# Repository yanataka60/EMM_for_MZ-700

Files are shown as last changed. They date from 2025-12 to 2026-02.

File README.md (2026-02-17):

# EMMボード for MZ-700

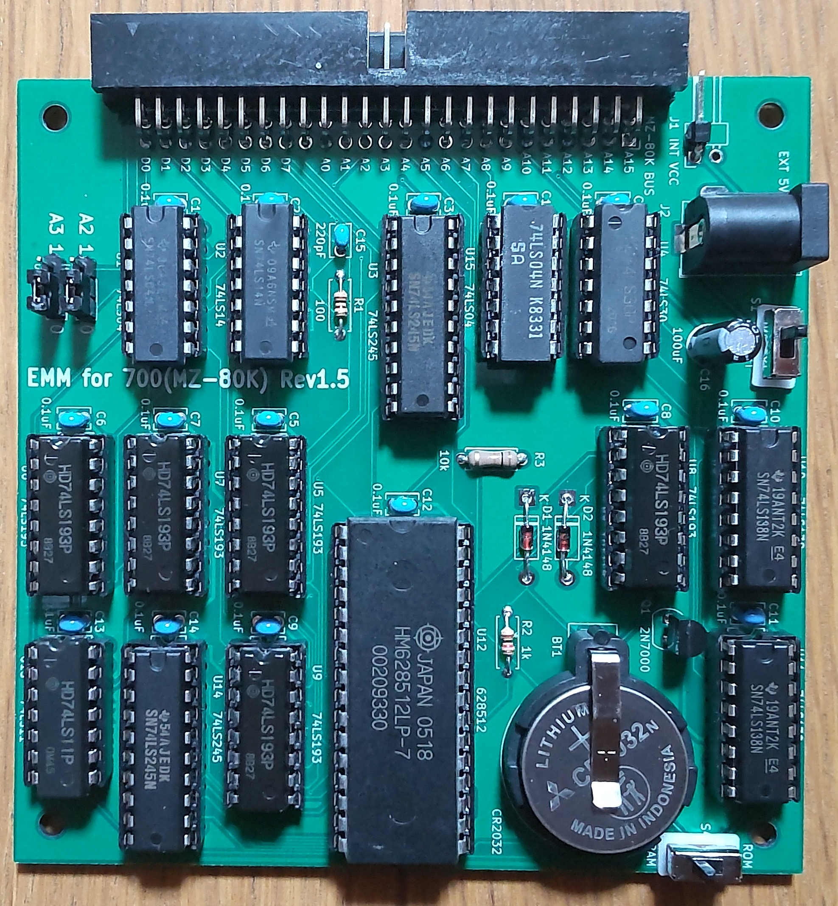
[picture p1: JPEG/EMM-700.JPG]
TITLE


　MZ-700、MZ-80K、MZ-80C、MZ-1200、MZ-1500用の512K S-RAM EMMボードを作ってみました。

　EMMが対応しているHuBASICはMZ-700用だけです。MZ-80K用、MZ-1500用HuBASICはEMMに対応していないので外部記憶装置として使うためにはI/Oポートを直接制御して読み書きする必要があります。

　特徴としては、

　1)I/Oポートは、I・Oデータ機器 PIO-3034互換なのでそのままPIO-3034(320K EMM)として使えます。

　2)CR-2032のバックアップにより電源を切ってもメモリ内容が保持されます。(Rev1.5のバックアップ期間は計算上数年は大丈夫です。)

　3)スイッチにより書込み禁止にできます。

　4)I/Oポートから直接EMMを読み書きすれば512K外部RAMとして使えます。

　5)MZ-700_SD、MZ-80K_SD、MZ-1500_SDと併用すれば512KまるごとSDカードからLOAD、SAVEが可能です。

　6)ジャンパによりEMM0～EMM3のいずれかに設定して使えます。

　7)おまけでアドレスカウンタリセットを付けました。

#### 注)　出来ればMZ-700本体内から5Vを取り出し、EMMボードに供給してください。

#### 　　 電源アダプタを接続しての外部電源で使用する場合には次の順序で電源の入り切りを行わないとバックアップが正常に行われません。ただし、S4スイッチがROM側になっていれば電源入り切りの順番に影響されません。

#### 　　 1)電源を入れるときにはEMMボードより先にMZ-700本体の電源を入れる。

#### 　　 2)電源を切るときには先にEMMボードの電源を切ってからMZ-700本体の電源を切る。

　なお、MZ-700、MZ-80K、MZ-1500本体の通常の電源ON/OFFでの正常動作は確認していますが、電源ON/OFFを瞬間的に繰り返すような無理な使い方をするとEMMのバックアップが正常に動作しないことがあります。電源ON/OFFを瞬間的に繰り返すと電源ユニット(電源アダプタ)にもダメージが及ぶこともあるので電源ON/OFFは間をおいて行ってください。

## 回路図
[回路図](https://github.com/yanataka60/EMM_for_MZ-700/blob/main/KiCad/MZ700_EMM.pdf)
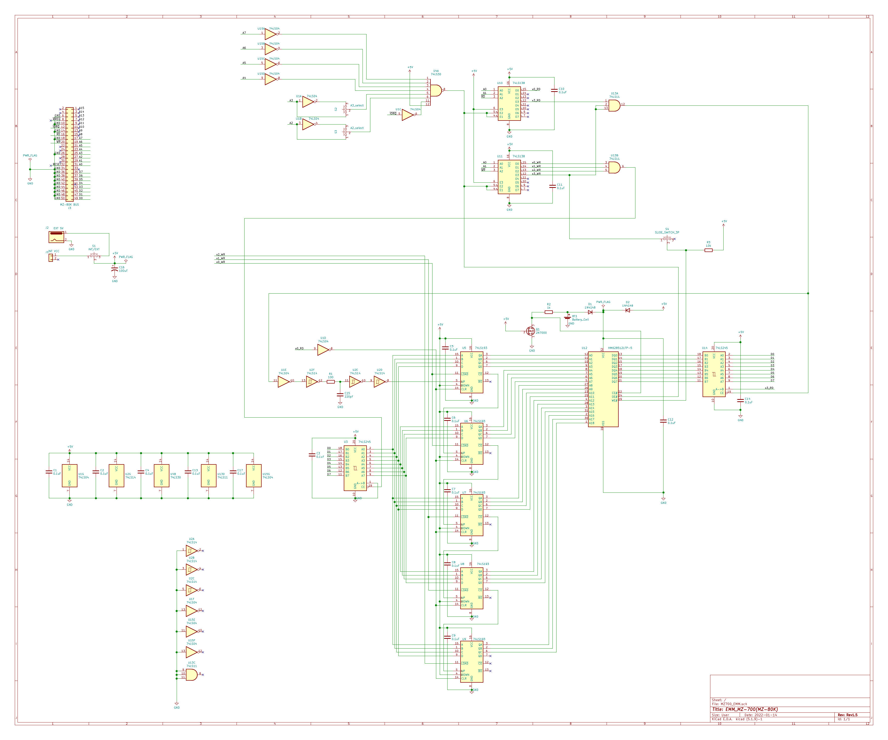
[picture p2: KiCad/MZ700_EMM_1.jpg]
回路図


## 部品表
|番号|品名|数量|備考|
| --- | --- | --- | --- |
|C1-C14,C17|積層セラミックコンデンサ 0.1uF|15||
|C15|積層セラミックコンデンサ 220pF|1||
|C16|電解コンデンサ 100uF|1||
|D1-D2|ダイオード 1N4148|2|1S4から1N4148に変更|
|Q1|FET 2N7000|1||
|J1|コネクタ 2Pin|1|ピンヘッダで代用するときはGNDと間違えないよう1Pinで5Vだけにしたほうが良い|
|J2|DCジャック|1||
|R1|カーボン抵抗 100Ω|1||
|R2|カーボン抵抗 1k|1||
|R3|カーボン抵抗 10k|1||
|S1|3Pスライドスイッチ|1|秋月電子通商 SS12D01G4など|
|S2,S3|3Pスライドスイッチ又は1x3ピンヘッダとジャンパーピン|1|秋月電子通商 SS12D01G4又はPH-1X3SG,MJ-254-6BK等|
|S4|3Pスライドスイッチ|1|秋月電子通商 SS12D01G4など|
|U1,U15|74LS04|2|樫木総業等|
|U2|74LS14|1|樫木総業等|
|U3,U14|74LS245|2|樫木総業等|
|U4|74LS30|1|樫木総業等|
|U5-U9|74LS193|5|樫木総業等|
|U10,U11|74LS138|2|樫木総業等|
|U12|SRAM HM628512|1|注1)|
|U13|74LS11|1|樫木総業等|
|BT1|ボタン電池基板取付用ホルダー CR2032用(小型タイプ)|1|秋月電子通商 CH25-2032LFなど|

注1)DIPで設計しています。SOPを入手した場合にはこちらの変換基板を使うことで装着できます。

https://github.com/yanataka60/SOPtoDIP32

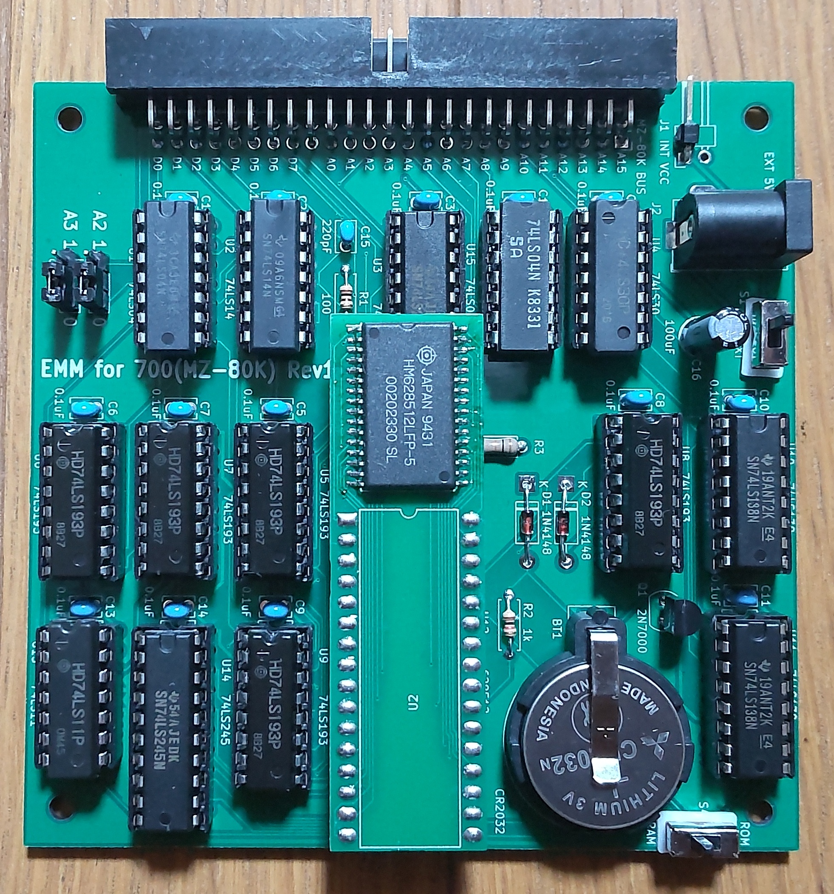
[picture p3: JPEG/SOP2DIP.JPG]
SOP2DIP


## I/Oポート
### EMM0
ジャンパピンA3、A2とも0の位置にします。

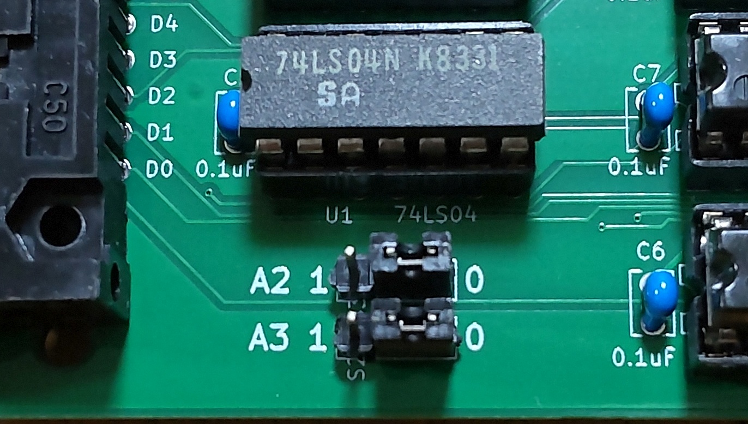
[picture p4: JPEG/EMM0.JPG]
EMM0


|アドレス|R/W|説明|
| --- | --- | --- |
|00h|R|アドレスカウンタリセット|
|00h|W|アドレスカウンタ Bit[7:0]|
|01h|W|アドレスカウンタ Bit[15:8]|
|02h|W|アドレスカウンタ Bit[18:16]|
|03h|R|データ読み出し:アドレスカウンタ+1|
|03h|W|データ書き込み:アドレスカウンタ+1|
### EMM1
ジャンパピンA3を0、A2を1の位置にします。

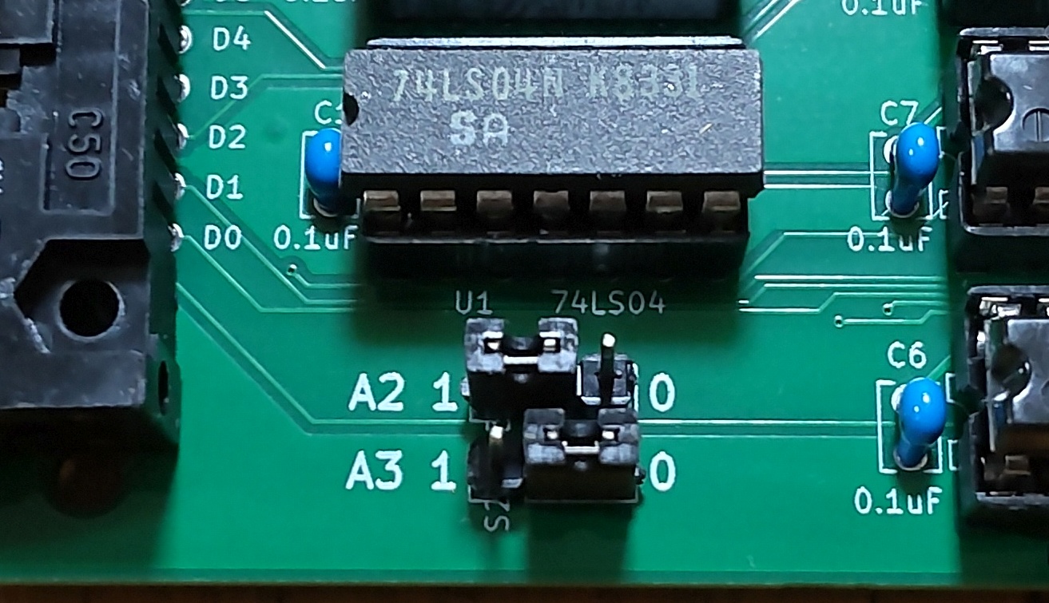
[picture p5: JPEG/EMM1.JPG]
EMM1


|アドレス|R/W|説明|
| --- | --- | --- |
|04h|R|アドレスカウンタリセット|
|04h|W|アドレスカウンタ Bit[7:0]|
|05h|W|アドレスカウンタ Bit[15:8]|
|06h|W|アドレスカウンタ Bit[18:16]|
|07h|R|データ読み出し:アドレスカウンタ+1|
|07h|W|データ書き込み:アドレスカウンタ+1|
### EMM2
ジャンパピンA3を1、A2を0の位置にします。

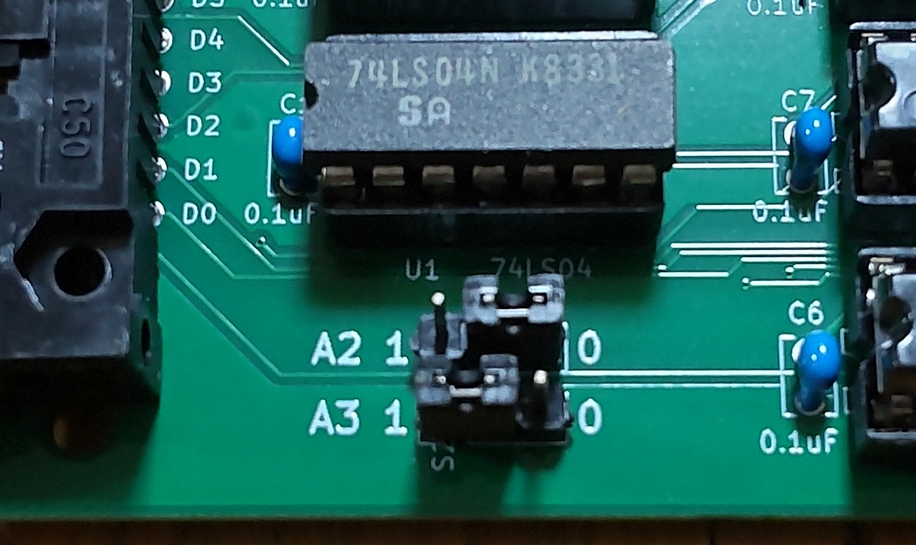
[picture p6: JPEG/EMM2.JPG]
EMM2


|アドレス|R/W|説明|
| --- | --- | --- |
|08h|R|アドレスカウンタリセット|
|08h|W|アドレスカウンタ Bit[7:0]|
|09h|W|アドレスカウンタ Bit[15:8]|
|0Ah|W|アドレスカウンタ Bit[18:16]|
|0Bh|R|データ読み出し:アドレスカウンタ+1|
|0Bh|W|データ書き込み:アドレスカウンタ+1|
### EMM3
ジャンパピンA3、A2とも1の位置にします。

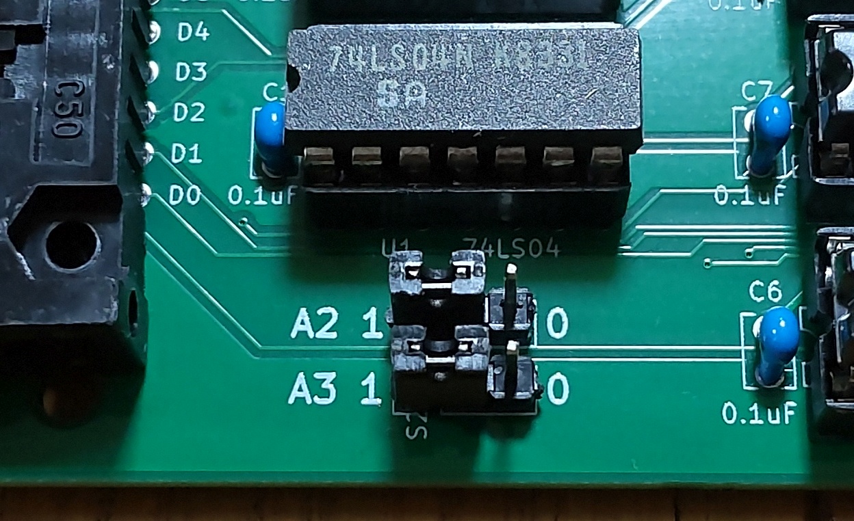
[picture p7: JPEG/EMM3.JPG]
EMM3


|アドレス|R/W|説明|
| --- | --- | --- |
|0Ch|R|アドレスカウンタリセット|
|0Ch|W|アドレスカウンタ Bit[7:0]|
|0Dh|W|アドレスカウンタ Bit[15:8]|
|0Eh|W|アドレスカウンタ Bit[18:16]|
|0Fh|R|データ読み出し:アドレスカウンタ+1|
|0Fh|W|データ書き込み:アドレスカウンタ+1|

## SAMPLEプログラム
　SAMPLEフォルダ内にEMMMENU、EMMCHECK、EMMTESTを置きました。

　使い方については、フォルダ内のREADME.mdを参照してください。

## EMMからの起動
　せっかくバッテリーバックアップに対応させたのでMZ-700_SD、MZ-1500_SDからコマンド「FDE0」～「FDE3」を使うことで「EMM0」～「EMM3」のHuBASICを起動できるようにしてみました。

　MZ-700_SD、MZ-1500_SDのROMをEMM対応に書き換える必要があります。

　MZ-700_SD、MZ-1500_SDの「EMMボード for MZ-700からの起動」を参照してください。

　https://github.com/yanataka60/MZ-700_SD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

　https://github.com/yanataka60/MZ-1500_SD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

## 初期基板をバッテリーバックアップ対応とするには
#### 2026.2.17 Rev1.5基板ではバックアップ時間が飛躍的に増加し、ICに負荷をかけない回路となりました。バッテリーバックアップを使うなら出来ればRev1.5基板に更新してください。

　以下に示すパターンカット、ジャンパ、追加部品(抵抗10k×1本、ダイオード1S4×1本)で改造することで初期基板をバッテリーバックアップ対応とすることが可能です。

　ただし、パターンカット個所がU13 74LS11、U15 74LS04のICソケット内側にもあるのでEMMボード組み立て済みの場合にはICソケットを一旦取り外す必要があります。

### パターンカット個所
　U13 74LS11の9Pin、10Pin、11PinをGNDから切り離します。

　U15 74LS04の11Pin、13PinをGNDから切り離します。

　U12 HM628512の29PinとU11 74LS138 12Pinとの接続をカットします。

　U12 HM628512の22、24Pin、R2 10Kとの接続点とU11 74LS138 5Pinとの接続をカットします。

部品面全体
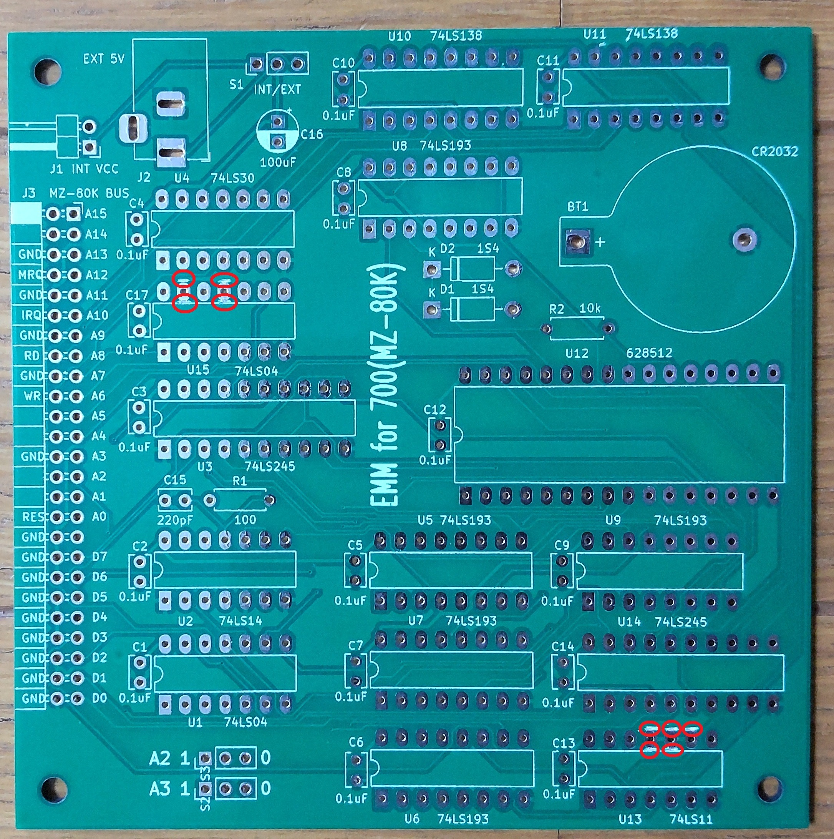
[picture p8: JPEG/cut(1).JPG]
cut1


部品面拡大1
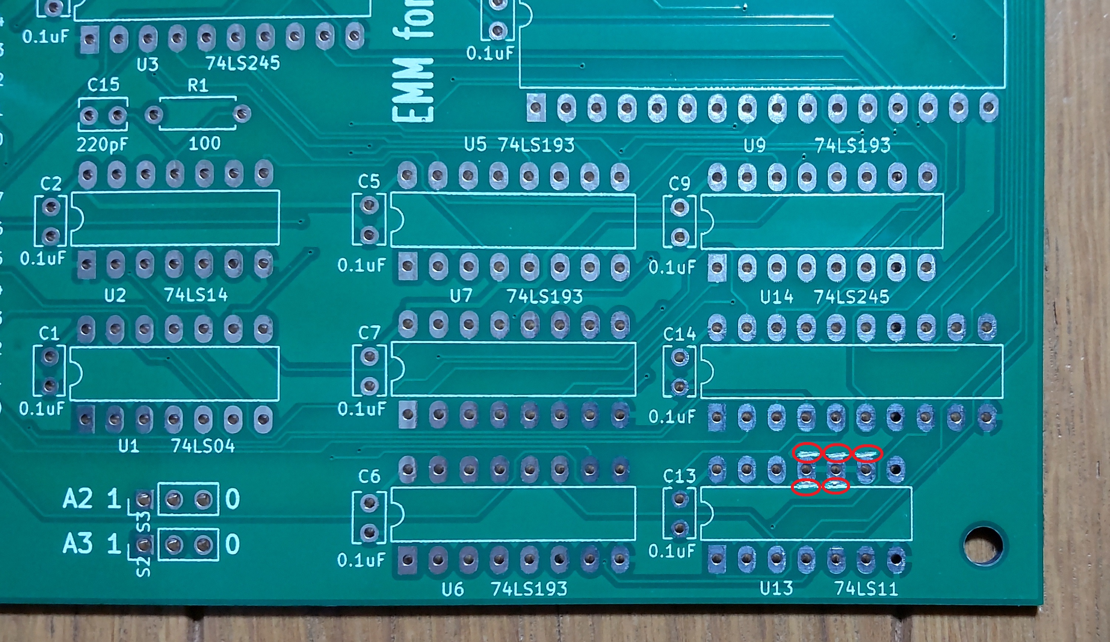
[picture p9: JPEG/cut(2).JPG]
cut2


部品面拡大2
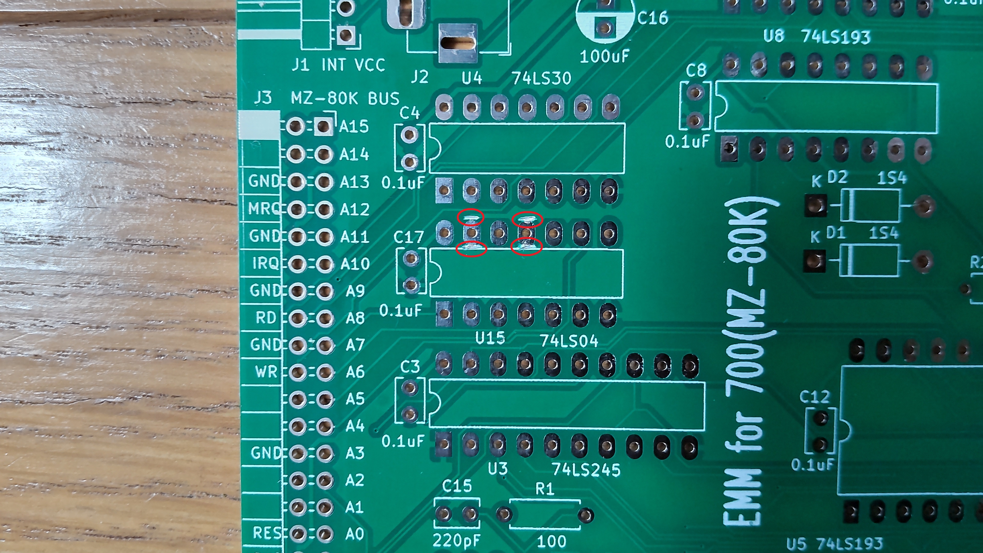
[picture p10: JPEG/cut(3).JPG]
cut3


ハンダ面全体
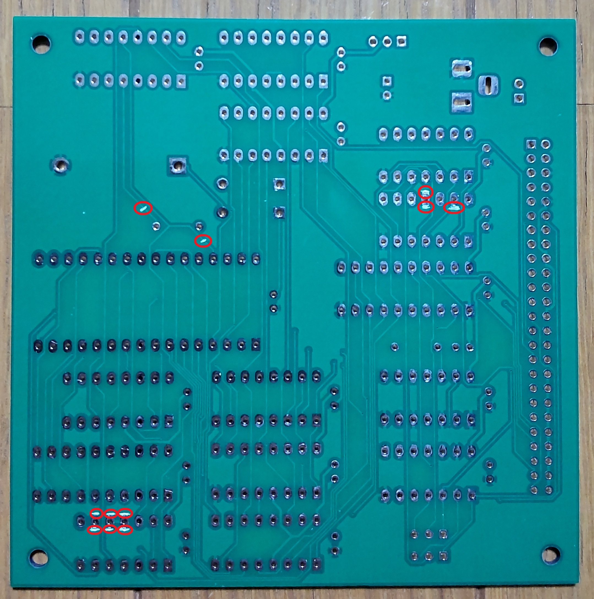
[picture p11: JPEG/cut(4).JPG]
cut4


ハンダ面拡大1
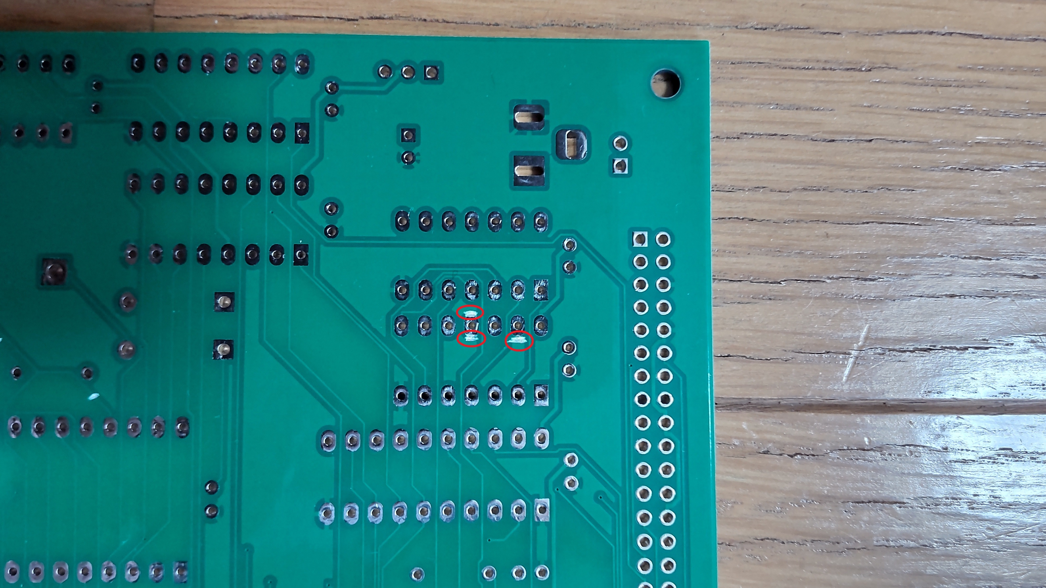
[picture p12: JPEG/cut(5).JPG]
cut5


ハンダ面拡大2
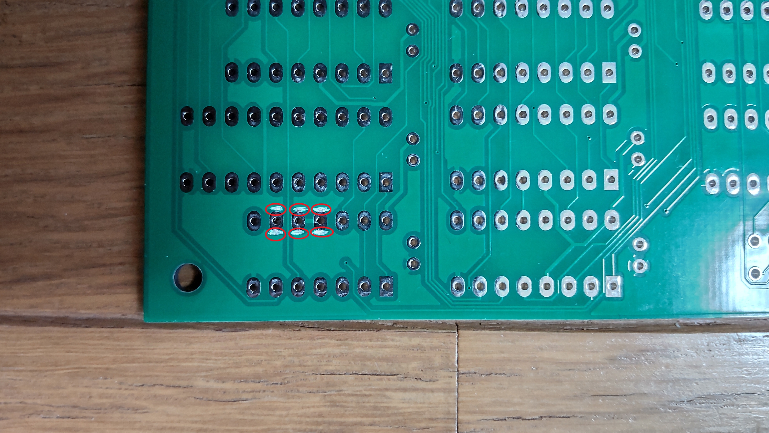
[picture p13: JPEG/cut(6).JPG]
cut6


ハンダ面拡大3
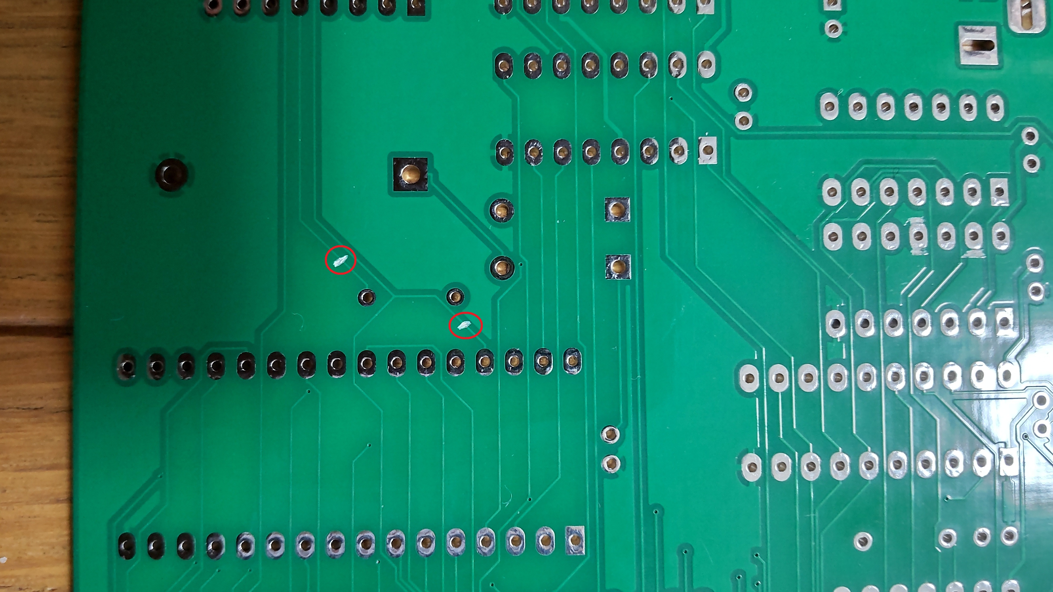
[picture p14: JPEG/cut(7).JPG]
cut7


### ジャンパ個所
　U11 74LS138 5PinとU13 74LS11 11Pin

　U13 74LS11 8PinとU12 HM628512 24Pin(画像ではR2 10KのU12 HM628512 24Pinと接続されている方)

　U11 74LS138 12PinとU15 74LS04 13Pin

　U15 74LS04 12Pinと11Pin

　U15 74LS04 10Pinとダイオード 1S4 アノード

　ダイオード 1S4 カソードとU12 HM628512 29Pin

　U12 HM628512 29Pinと抵抗 10KとU12 HM628512 32Pin

ハンダ面全体
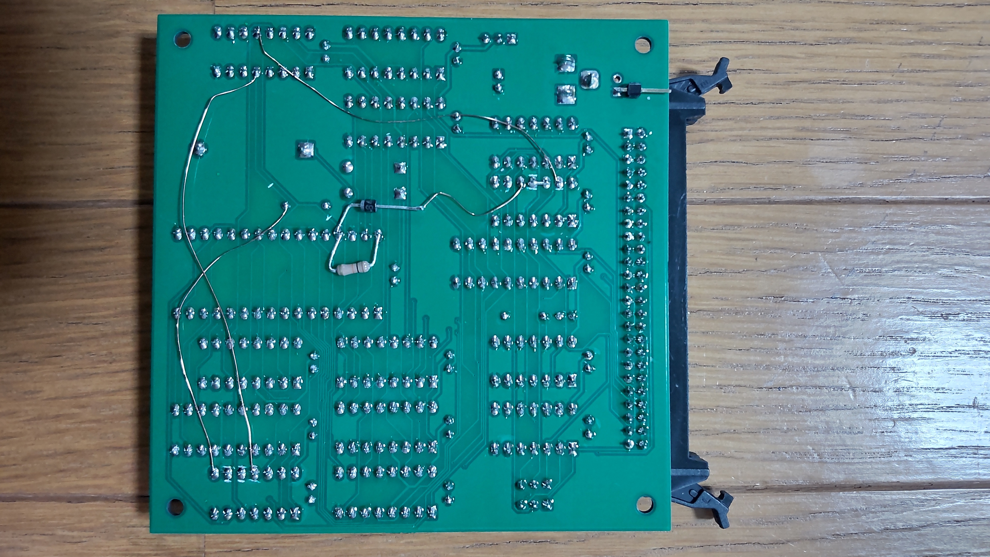
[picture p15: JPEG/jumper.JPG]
jumper


## 追記
2025.12.26 SAMPLEプログラムを追加しました。

2025.12.28 バッテリーバックアップしていてもメモリ内容が変わってしまう症状が時々発生しています。原因と対策を検討中です。

2026.1.1 簡単な修正では症状を抑えることが出来ないのでこのバージョンではバッテリーバックアップは断念し、対策を練りなおします。

2026.1.23 バッテリーバックアップ正常版(Rev1.2)に更新。初期基板をバッテリーバックアップ対応とするための改修方法を記述。

2026.1.23 バックアップ期間について追記。

2026.1.24 HM628512の書き込み時WE信号が瞬間的に5.9Vほどの電圧が掛かることを記述。すーぱーたーぼさんご指摘ありがとうございました。

2026.1.25 D1,D2を1S4から1N4148に変更。AIGOU Yoshiakiさんアドバイスありがとうございました。

2026.2.17 すーぱーたーぼさんに提案していただいていたn-FETを用いたバッテリーバックアップ回路を採用しました。すーぱーたーぼさんアドバイスありがとうございました。

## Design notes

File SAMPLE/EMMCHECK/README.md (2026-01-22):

# EMMCHECK for MZ-700_SD(MZ-80K_SD、MZ-1500_SD)

　EMMボートの512K S-RAMの内容とMZ-700_SD(MZ-80K_SD、MZ-1500_SD)のファイルの内容を比較します。

　MZ-700、MZ-80K、MZ-80C、MZ-1200、MZ-1500で実行可能です。

　バッテリーバックアップが正常に機能しているかチェックするためのプログラムです。

　起動するとまず対象とするEMMをEMM0～EMM3の中から数字で選択します。

　次に比較するファイルを指定します。

　「FNAME:」と聞いてきますので次のうちから選択して入力します。

### [BREAK]キー
　処理が中断されたものとしてMONITOR入力待ちに戻ります。

### DOSファイル名を入力せずそのまま[CR]キー
　選択したEMMに対応するPIO3034_x.mzt(PIO3034_0.mzt、PIO3034_1.mzt、PIO3034_2.mzt、PIO3034_3.mzt)をDOSファイル名として比較します。

### DOSファイル名を入力して[CR]キー
　入力されたDOSファイル名のファイルと比較とします。拡張子の「mzt」は省略可能です。

### *FDL xxx[CR]キー
　SDカードに保存されている文字列xxxから始まるDOSファイル名を一覧表示します。xxxを省略した場合はすべてのファイルが一覧表示対象となります。

　20件表示したところで指示待ちになるので打ち切るならSHIFT+BREAK又は↑を入力すると打ち切られ、Bキーで前の20件に戻ります。それ以外のキーで次の20件を表示します。

　検索結果の行頭には「FNAME:」を付加して表示してあるので比較したいファイルにカーソルキーを合わせて[CR]キーを押すだけで選択が可能です。

例)

FNAME:[CR]

FNAME:PIO-3034EMM1[CR]

FNAME:*FDL PIO[CR]

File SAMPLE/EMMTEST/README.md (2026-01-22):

# EMMTEST

　EMMボートの512K S-RAMの読み書きテストプログラムです。

　MZ-700、MZ-80K、MZ-80C、MZ-1200、MZ-1500で実行可能です。

　RAMの内容を一時退避しながらテストしますのでRAMの読み書きが正常であればEMMの内容が変化してしまうことはありません。

　起動すると対象とするEMMをEMM0～EMM3の中から数字で選択するとテストが始まります。(00000h～7FFFFh)

　書き込んだ内容が正常に読み出せない場合にはエラーと表示して停止します。

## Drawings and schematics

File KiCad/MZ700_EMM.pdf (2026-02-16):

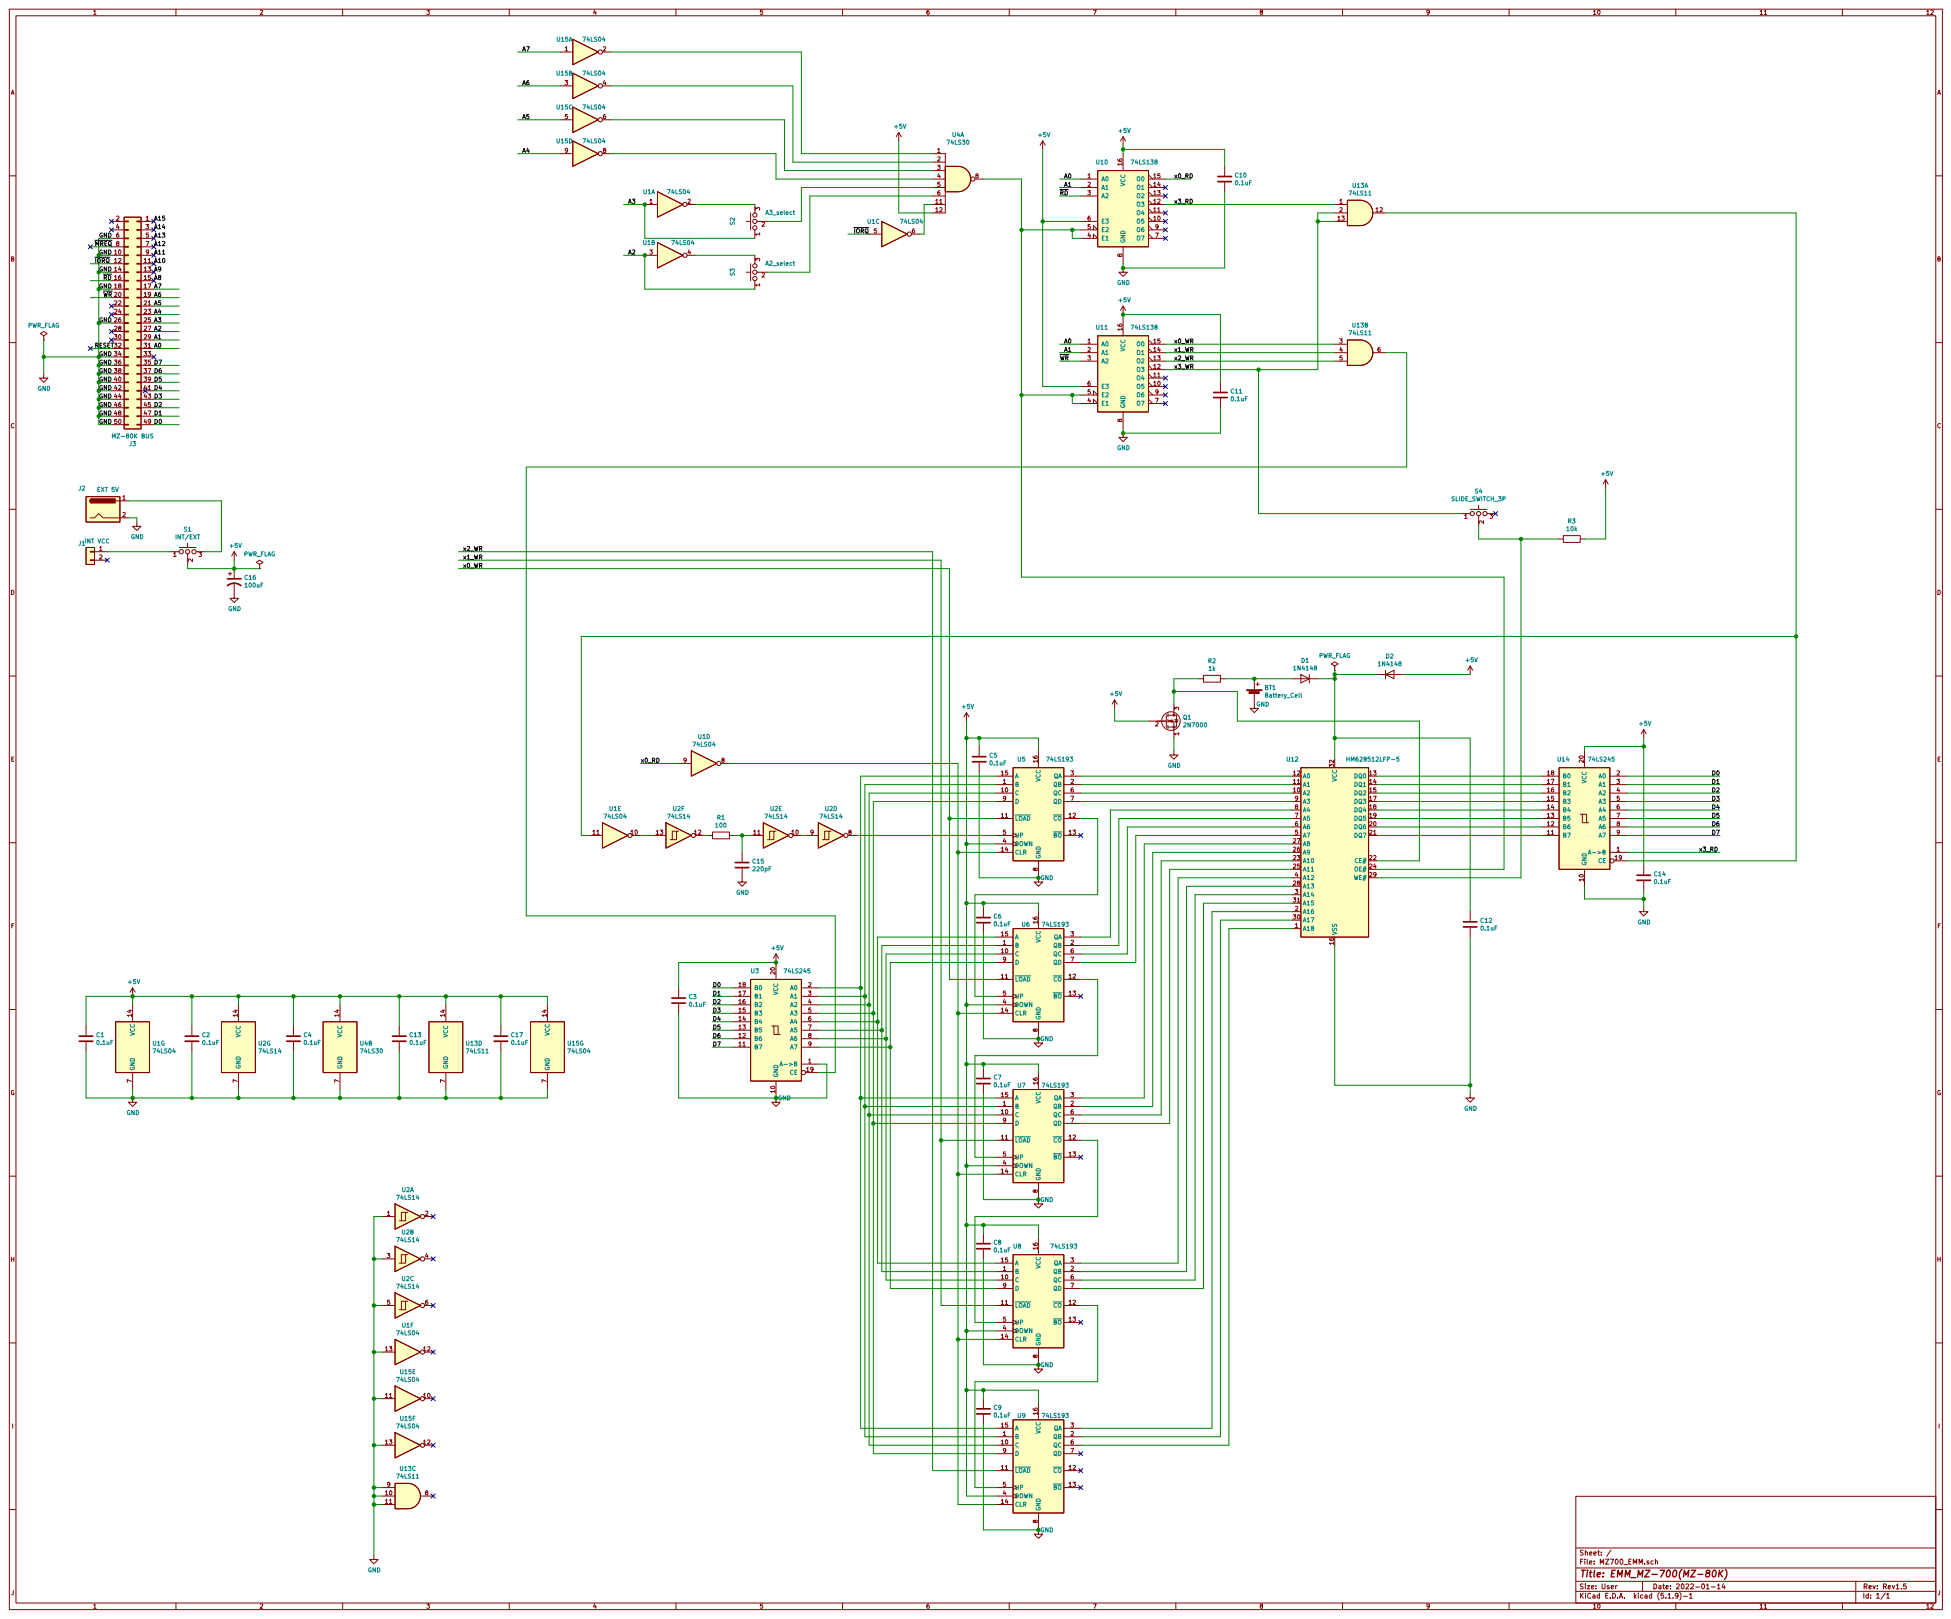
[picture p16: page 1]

GND GNDWR GND GND

RESET GND GND GND GND GND

14 O0 x1_WR | 4
13 O1 x2_WR | 5
12 O2 x3_WR
11 O3

38 | 37
40 | 39
42 | 41
44 | 43
46 | 45
48 | 47
50 | 49

File: MZ700_EMM.sch Sheet: / VCC 14 GND

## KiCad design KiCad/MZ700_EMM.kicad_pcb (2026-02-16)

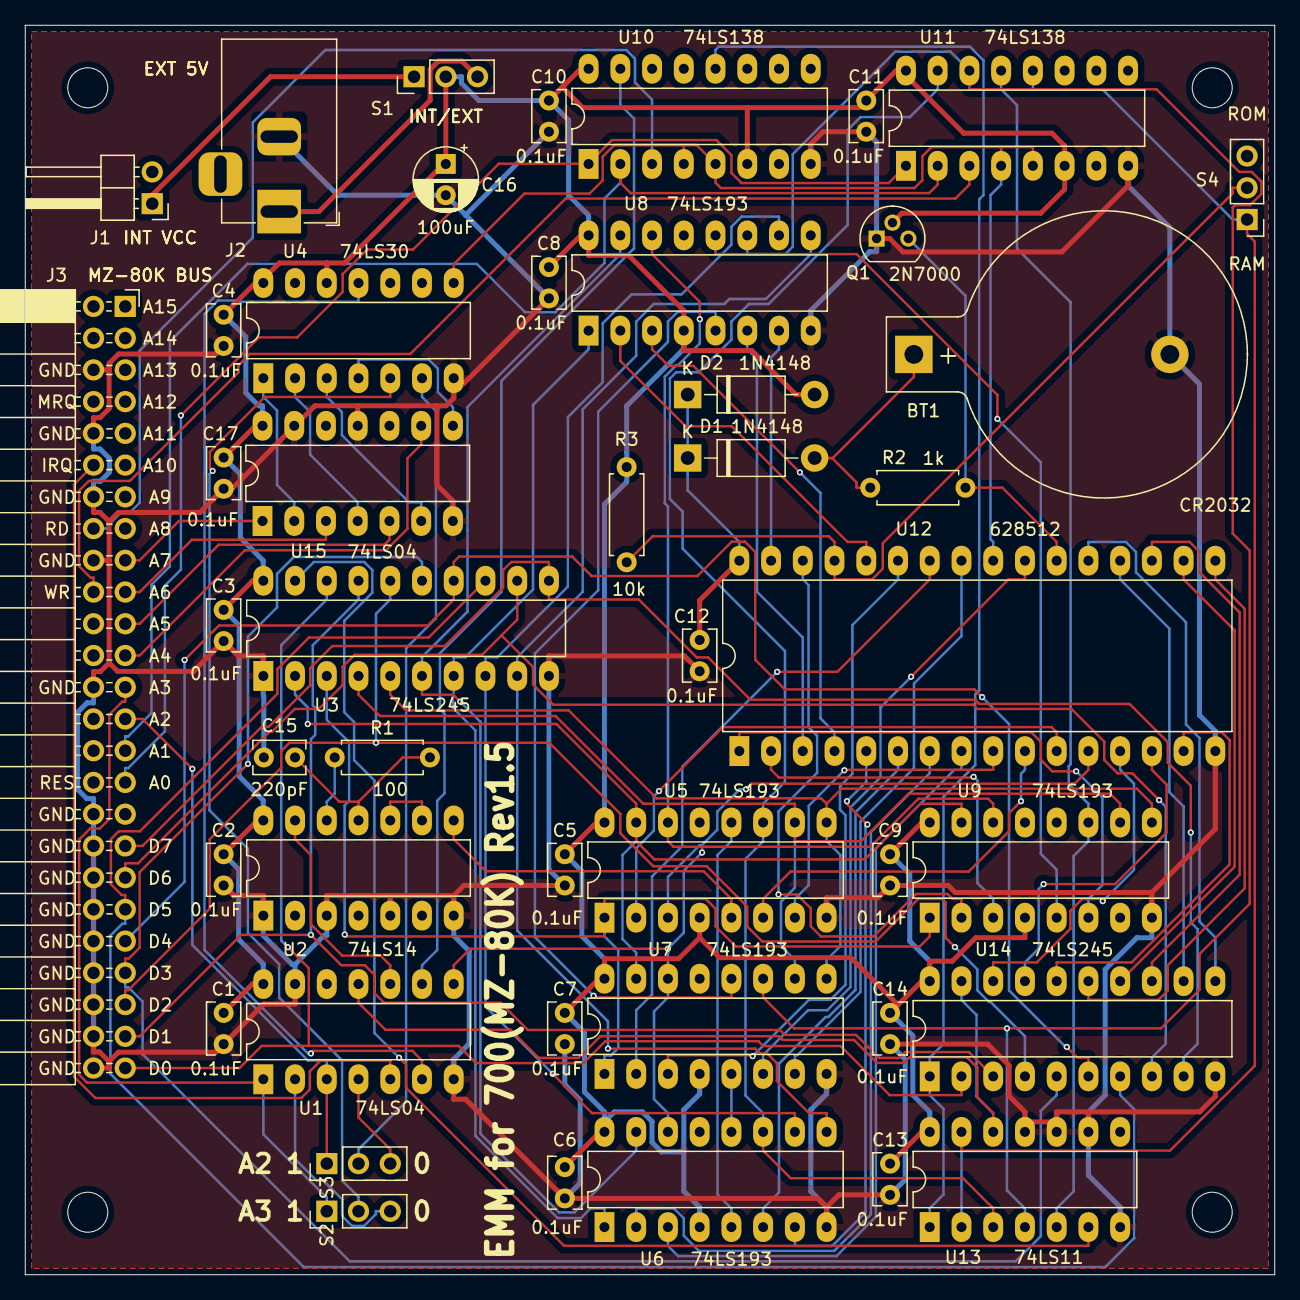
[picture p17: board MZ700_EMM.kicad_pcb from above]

Board: 2 copper layers, 100.0 x 100.0 mm, 50 parts (0 on the bottom side), 90 nets.

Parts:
BT1: Battery_Cell; BatteryHolder_Keystone_103_1x20mm
C1, C2, C3, C4, C5, C6, C7, C8, C9, C10, C11, C12, C13, C14, C17: 0.1uF; C_Rect_L4.0mm_W2.5mm_P2.50mm
C15: 220pF; C_Rect_L4.0mm_W2.5mm_P2.50mm
C16: 100uF; CP_Radial_D5.0mm_P2.50mm
D1, D2: 1N4148; D_DO-41_SOD81_P10.16mm_Horizontal
J1: INT VCC; PinHeader_1x02_P2.54mm_Horizontal
J2: EXT 5V; BarrelJack_Horizontal
J3: MZ-80K BUS; PinSocket_2x25_P2.54mm_Horizontal
MH1, MH2, MH3, MH4: MountingHole_3.2mm_M3
Q1: 2N7000; TO-92
R1: 100; R_Axial_DIN0207_L6.3mm_D2.5mm_P7.62mm_Horizontal
R2: 1k; R_Axial_DIN0207_L6.3mm_D2.5mm_P7.62mm_Horizontal
R3: 10k; R_Axial_DIN0207_L6.3mm_D2.5mm_P7.62mm_Horizontal
S1: INT/EXT; PinHeader_1x03_P2.54mm_Vertical
S2: A3_select; PinHeader_1x03_P2.54mm_Vertical
S3: A2_select; PinHeader_1x03_P2.54mm_Vertical
S4: SLIDE_SWITCH_3P; PinHeader_1x03_P2.54mm_Vertical
U1, U15: 74LS04; DIP-14_W7.62mm_LongPads
U2: 74LS14; DIP-14_W7.62mm_LongPads
U3, U14: 74LS245; DIP-20_W7.62mm_LongPads
U4: 74LS30; DIP-14_W7.62mm_LongPads
U5, U6, U7, U8, U9: 74LS193; DIP-16_W7.62mm_LongPads
U10, U11: 74LS138; DIP-16_W7.62mm_LongPads
U12: HM628512LFP-5; DIP-32_W15.24mm_LongPads
U13: 74LS11; DIP-14_W7.62mm_LongPads

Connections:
+5V: C1.1, C2.1, C3.1, C4.1, C5.1, C6.1, C7.1, C8.1, C9.1, C10.1, C11.1, C13.1, C14.1, C16.1, C17.1, D2.2, Q1.2, R3.2, S1.2, U1.14, U2.14, U3.20, U4.12, U4.14, U5.4, U5.16, U6.4, U6.16, U7.4, U7.16, U8.4, U8.16, U9.4, U9.16, U10.6, U10.16, U11.6, U11.16, U13.14, U14.20, U15.14
/A0: J3.31, U10.1, U11.1
/A1: J3.29, U10.2, U11.2
/A2: J3.27, S3.1, U1.3
/A3: J3.25, S2.1, U1.1
/A4: J3.23, U15.9
/A5: J3.21, U15.5
/A6: J3.19, U15.3
/A7: J3.17, U15.1
/D0: J3.49, U3.18, U14.2
/D1: J3.47, U3.17, U14.3
/D2: J3.45, U3.16, U14.4
/D3: J3.43, U3.15, U14.5
/D4: J3.41, U3.14, U14.6
/D5: J3.39, U3.13, U14.7
/D6: J3.37, U3.12, U14.8
/D7: J3.35, U3.11, U14.9
/x0_RD: U1.9, U10.15
/x0_WR: U5.11, U6.11, U11.15, U13.3
/x1_WR: U7.11, U8.11, U11.14, U13.4
/x2_WR: U9.11, U11.13, U13.5
/x3_RD: U10.12, U13.1, U14.1
/x3_WR: S4.1, U11.12, U13.2, U13.13
/~IORQ: J3.12, U1.5
/~RD: J3.16, U10.3
/~WR: J3.20, U11.3
GND: BT1.2, C1.2, C2.2, C3.2, C4.2, C5.2, C6.2, C7.2, C8.2, C9.2, C10.2, C11.2, C12.2, C13.2, C14.2, C15.2, C16.2, C17.2, J2.2, J3.6, J3.10, J3.14, J3.18, J3.26, J3.34, J3.36, J3.38, J3.40, J3.42, J3.44, J3.46, J3.48, J3.50, Q1.1, U1.7, U1.13, U2.1, U2.3, U2.5, U2.7, U3.1, U3.10, U4.7, U5.8, U6.8, U7.8, U8.8, U9.8, U10.8, U11.8, U12.16, U13.7, U13.9, U13.10, U13.11, U14.10, U15.7, U15.11, U15.13
unnamed: BT1.1, D1.2, R2.2
unnamed: C12.1, D1.1, D2.1, U12.32
unnamed: C15.1, R1.2, U2.11
unnamed: J1.1, S1.1
unnamed: J2.1, S1.3
unnamed: Q1.3, R2.1, U12.22
unnamed: R1.1, U2.12
unnamed: R3.1, S4.2, U12.29
unnamed: S2.2, U4.5
unnamed: S2.3, U1.2
unnamed: S3.2, U4.6
unnamed: S3.3, U1.4
unnamed: U1.6, U4.11
unnamed: U1.8, U5.14, U6.14, U7.14, U8.14, U9.14
unnamed: U1.10, U2.13
unnamed: U1.11, U13.12, U14.19
unnamed: U2.8, U5.5
unnamed: U2.9, U2.10
unnamed: U3.2, U5.15, U7.15, U9.15
unnamed: U3.3, U5.1, U7.1, U9.1
unnamed: U3.4, U5.10, U7.10, U9.10
unnamed: U3.5, U5.9, U7.9, U9.9
unnamed: U3.6, U6.15, U8.15
unnamed: U3.7, U6.1, U8.1
unnamed: U3.8, U6.10, U8.10
unnamed: U3.9, U6.9, U8.9
unnamed: U5.12, U6.5
unnamed: U6.12, U7.5
unnamed: U7.12, U8.5
unnamed: U8.12, U9.5
unnamed: U4.8, U10.4, U10.5, U11.4, U11.5, U12.24
unnamed: U9.6, U12.1
unnamed: U9.3, U12.2
unnamed: U8.6, U12.3
unnamed: U8.3, U12.4
unnamed: U6.7, U12.5
unnamed: U6.6, U12.6
unnamed: U6.2, U12.7
unnamed: U6.3, U12.8
unnamed: U5.7, U12.9
unnamed: U5.6, U12.10
unnamed: U5.2, U12.11
unnamed: U5.3, U12.12
unnamed: U12.13, U14.18
unnamed: U12.14, U14.17
unnamed: U12.15, U14.16
unnamed: U12.17, U14.15
unnamed: U12.18, U14.14
unnamed: U12.19, U14.13
unnamed: U12.20, U14.12
unnamed: U12.21, U14.11
unnamed: U7.6, U12.23
unnamed: U7.7, U12.25
unnamed: U7.2, U12.26
unnamed: U7.3, U12.27
unnamed: U8.2, U12.28
unnamed: U9.2, U12.30
unnamed: U8.7, U12.31
unnamed: U3.19, U13.6
unnamed: U4.1, U15.2
unnamed: U4.2, U15.4
unnamed: U4.3, U15.6
unnamed: U4.4, U15.8
